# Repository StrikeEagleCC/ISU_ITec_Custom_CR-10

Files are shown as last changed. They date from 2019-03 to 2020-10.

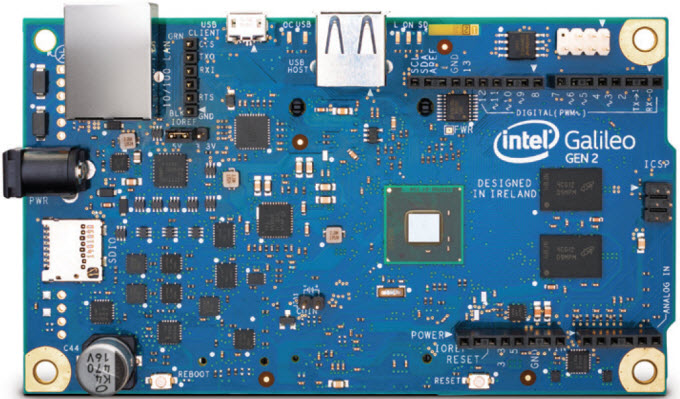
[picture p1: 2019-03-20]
Arduino Windows Preconfigured/reference/Edison_help_files/Guide_Windows_html_14b9dfe7.jpg

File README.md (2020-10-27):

# ISU_ITec_Custom_CR-10
Firmware, information, and slicer profiles for the ISU ITec club custom Creality CR-10's
https://github.com/StrikeEagleCC/ISU_ITec_Custom_CR-10

## 2020 UPDATE
- Switched to a flexible, removable magnetic print surface
- Restored full build volume through better implementation of homing and mesh probing
- Reverted back to bed springs instead of nylon spacers to reduce severity of crashes, and used better-than-stock springs
- [New and Improved slicer profiles!](https://github.com/StrikeEagleCC/ISU_ITec_Custom_CR-10/tree/master/Slicer%20Profiles)
- Replaced Slic3r profiles with PrusaSlicer profiles

To make additional changes to the firmware simple, I have included in this repository a portable installation of the Arduino IDE which has been preconfigured to work for Creality CR and Ender series printers. To edit the firmware, download this repository and open "OpenFirmwareWindows.bat"

Special thanks to Michael from the YouTube channel [Teaching Tech](https://www.youtube.com/channel/UCbgBDBrwsikmtoLqtpc59Bw) and Chris from [TH3D](https://www.th3dstudio.com/) for their excellent guides and other resources. And of course, to the Marlin developer community for all of their excellent work.

---

The two Creality CR-10s belonging to the ISU Itec Club Robotics Team have been modified in several notable ways that you should be aware of.

## The most important things to know are:

1. **Add `G29` to your starting scripts!** (But only after commands to fully heat the bed, i.e. M190)
1. **The flexible magnetic print surfaces work well for PLA and PETG. However, you can still use the ULTRABASE glass surface. Simply remove the magnetic sheet and replace with the glass.**
1. **When placing the manetic print surface on the bed, ensure there is no debris between the print surface and the bed. This is especially important if the printers continue to be stored in the CNC lab, as metal chips will be attracted to the magnetic surfaces.**
1. **Do not use metal scrapers on the ULTRABASE glass print surface! Allow it to cool completely and parts will pop off easily.** If parts are not coming off easily, the first layer may be getting too squashed.
1. **If using the glas print surface, don't attempt to print close to the front or back edge of the bed. The print head will hit the clips that hold the glass to the bed.**
1. **The shape of the bed will continue to change for several minutes after preheating has completed. Allow several minutes at full temperature before starting the bed-leveling probing.** This can be done by adding delays to starting scripts. Read more below.
1. **The bed leveling knobs do not need to be adjusted. They have been carefully set and locked with jam nuts. Any remaining out-of-level condition should be compensated for by the BLTouch probe and software bed leveling**
1. **The height of the nozzle above the bed can be adjusted from the menus to dial in the height of the first layer in real time:**
    1. _Control>Motion>Probe Z Offset_
    1. **Or** by double-clicking or long-clicking the control knob during a print (making live adjustments this way is called "baby-stepping")
1. **Each printer controller is paired with a particular printer frame due to the** **_Probe Z Offset_**  **setting being unique to each printer. Don't mix them up.** I have labeled both frames and both controllers to make this obvious.

The modifications on these machines were made for the sake of adding several desirable features for both safety and functionality. However, given the low price point of the printers, some trade-offs had to be made. I'll list new features and lost features below, and then discuss in further detail. The changes included some new hardware, modification of original hardware, and installation of a customized version of the Marlin firmware

**New Features**

- Thermal runaway protection for both bed and extruder
- BLtouch probe
- Automatic mesh bed leveling
- Linear pressure control
- Filament runout detection
- Persistent settings

**Lost Features**

- Buzzer no longer functional
- Some menu items no longer visible
  - Any functions for which menu items were removed are still accessible through Gcode, either through GCode files or through a serial console like pronterface or Simplify3D's machine control panel.
- No arc support
- No volumetrics

---

### New Features In Detail

#### Thermal Runaway Protection
Thermal runaway protection is an important safety feature that was not included in the original printer firmware. This feature prevents the bed or extruder from overheating in the event that a temperature sensor fails. This type of failure has been the cause of 3D printer fires in the past, and is now widely considered to be a critical safety feature. This is just a software feature, and required no hardware modifications. This feature also requires no interaction with the user. [Read more here.](http://marlinfw.org/docs/configuration/configuration.html#safety)

#### BLTouch Probe
The BLTouch probe is the device on the hotend carriage with the red light in it. This device uses a small solenoid, a pin, and a hall effect sensor to measure the position of the print bed relative to the nozzle. In the simplest implementation, it just replaces the Z-axis limit switch, but its true value is that it facilitates automatic mesh bed leveling.

**Using a Z-axis probe creates an additional and very important setting, _Probe Z Offset_.** This setting represents the distance between the probe's measurement point and the bottom of the nozzle. It can be adjusted from the menus _Control>Motion>Probe Z Offset_ or by double-clicking or long-clicking the control wheel during a print. This is extremely handy to make fine adjustments to the nozzle height during the first layer.

Under some circumstances, the probe may encounter an error and begin flashing. This error can be cleared by either power cycling the printer or navigating to the BLTouch sub menu and resetting it: _Control>BL Touch>Reset BL Touch_

Installing the probe requires the use of a pin on the printer's microprocessor which was previously used to sound the buzzer. To make the use of the probe possible, the buzzer has been disabled, and the pin repurposed for use with the probe.Read more about [probes in Marlin](http://marlinfw.org/docs/configuration/configuration.html#z-probe-options) and more about the [BLTouch](https://www.antclabs.com/bltouch).

#### Automatic Mesh Bed Leveling
Auto bed leveling is a process that makes it possible to get reliable first layers, even on beds that aren't perfectly flat or level. This is done by taking several z-axis measurements of the print bed when starting a print. The printer then uses these measurements to build a map of the print bed, then automatically adjusts the nozzle height during printing to conform to the shape of the bed. This effect can be gradually faded out so that after a short vertical distance it is no longer in effect.

Mesh bed leveling compensates both for beds that aren't flat and beds that aren't level. This means that the bed doesnt have to be perfectly level. As long as the jam nuts beneath the leveling knobs are snug, no adjustment should be needed.

**An important limitation** of thes printers is the cantilevered design of the X-axis gantry. Because the Z leadscrew only pushes on the left side of the X gantry, there is some movement hysteresis (backlash) on the right side. This hysteresis can have a negative impact on the effectiveness of bed leveling, since the probing is done with the gantry moving downwards, and the prints are done with the gantry moving upwards. In practice, I find that even after an automatic bed leveling, my first layers are a bit thinner on the right side of the bed than on the left. Some careful adjustment of the X-axis gantry rollers has improved this somewhat. Still, it's better than stock in that it compensates for the non-planer shape of the bed. **Don't attempt first layers thinner than 0.2mm unless the print is very small** The thicker the first layer is, the more room there is for error here.

Mesh bed leveling should be performed at the beginning of every print. This is done by adding a `G29` command in the starting script in the slicer _after_ the bed has finished heating. Failure to add this will almost certainly lead to first layer failure, may lead to a crash and to nozzle or bed damage. Also, as noted previously, the bed will continue to change shape for several minutes after preheating has completed. This is due primarily to thermal expansion and the time it takes for the bed temperature to even out. To allow for this, add a delay before `G29` in the starting script with `G4 P<time in milliseconds>`. Delays greater than 60 seconds may cause problems in some scenarios, so for a 5 minute delay, add `G29 P60000` five times in the starting script.

Mesh bed leveling is done in software, but requires the use of a probe such as the BLTouch. You can [read more about it here](http://marlinfw.org/docs/configuration/configuration.html#bed-leveling).

#### Linear Pressure Control
Also called Linear Advance, this feature aims to improve print quality by controlling the pressure in the nozzle. This is done by adding compression to the filament in an amount proportional to the extrusion velocity and a controlled by a constant factor configurable in the machine settings. There is a lot of interesting [information available about it here](http://marlinfw.org/docs/features/lin_advance.html), but here's what you need to know:

Linear advance causes a lot of extruder motor movement. If you're familiar with FDM machines, the movement of the extruders on these modified machines may surprise you. The setting to control the amount of linear advance is in _Control>Filament>Advance K_, or by issuing a `M900 K<factor>`. A factor of 0.6 works well for PLA on these printers. Changing this setting to zero will disable the feature. If disabled, you will need to increase retraction distances in the slicer to avoid stringing, and you can expect to see less detail and more blobs in corners than if the feature is enabled.

This feature is entirely software based and required no hardware modifications.

#### Filament Runout Detection
The purpose of filament runout detection is to stop a print in the event that your filament spool runs empty. This has been implemented on these printers with a custom filament sensor mounted on the extruder motor frame. Filament is fed through the sensor module and into the extruder. If the filament runs out, the sensor module will send a signal to the printer, which will stop the print, move the print head to a parking position, unload the filament and prompt the operator for action.

The park, unload, and prompt actions are part of a filament change sequence that can be manually commanded with a `M600` command. In fact, when the filament sensor detects a runout condition, the machine just gives itself an `M600`. You can execute this command deliberately from a console, or better yet, insert it into your gcode at strategic places to facilitate the use of multiple filament colors in a single print.

The current runout sensor that I designed is not very good. When the filament runs out, it usually jams in the sensor housing when the printer tries to automatically unload it. If this happens, cut the filament between the sensor and the extruder and pull the piece from the sensor out the extruder side. Heat up the extruder and then pull the remaining filament out from the extruder. Install the new filament as usual.

Also, if the filament is very curly when feeding it into the sensor, it can become snagged. Straighten the filament prior to threading it through.

If the sensor becomes damaged or unwanted, just unplug it. If you want to use a different sensor be aware that a firmware modification is likely to be necessary.

The filament sensor required the use of a pin on the microprocessor that was previously unused. A very small wire was soldered to this pin and used as the signal pin for the filament sensor. The M600 command is part of another feature called _Advanced Pause._ You can read more about filament runout sensors [here](http://marlinfw.org/docs/configuration/configuration.html#filament-runout-sensor) and about the advanced pause feature [here](http://marlinfw.org/docs/configuration/configuration.html#advanced-pause)

#### Persistent Settings
The original firmware on these printers did not support persistent settings. You could make changes to the settings from the menus or by issuing applicable commands, but if the printer was powered cycled, those settings would be replaced by the default values.

To store settings such as _Probe Z Offset_ or _Advance K_ (linear advance factor), navigate to _Control>Store Settings_, or issue an `M500` command from a console. Those settings will now persist through a reboot. To revert to the default settings, select _Restore failsafe_ or issue an `M502` command from a console. **Note** : **this will reset your _Probe Z-Offset_ to zero, and you will have to reset it!** Restoring default settings will not overwrite the stored settings unless you follow `M502` with `M500`

If you make changes to settings and want to revert them to the stored settings, just power cycle the printer or issue an `M501` command to restore the stored settings.

---

### Lost Features In Detail

#### Buzzer No Longer Functional
The buzzer was disconnected so that its control pin could be used for the Z probe

#### Some Menu Items No Longer Visible
Part of keeping the price of these printers low meant using inexpensive electronics. The microcontroller for the CR-10 (and most Creality printers) is cheap, and does not have enough memory to store a fully featured firmware. In order to make space for the new features, some other features were disabled. Most prominently, several menu items are gone.

The most noticeable menu items missing are feedrate, acceleration and jerk settings in the motion menu. Other settings no longer accessible through the menu include motor steps per mm, PID settings, material preset temps, and probably some others I haven't noticed.

These settings can still be changed with the appropriate g-code commands, and then saved to the EEPROM by sending `M500` or by navigating to _Control>Store settings_, you just won't be able to change the settings from the menu.

#### No Arc Support
Barely worth mentioning, since most slicers don't output arc commands by default. Disabled to save space.

#### No Volumetrics
Volumetric extrusion is a feature that allows gcode for a given print to specify the volume of plastic to be extruded through the nozzle, as opposed to the length of filament driven by the extruder. This allows the same g-code file to be used on multiple printers using different diameter filaments or different extruders. If you need it, then you probably know what it is, but it's rarely used. Disabled to save space.

### Printer Default Values

These are the default values that will be loaded if you click _Control>Restore failsafe_. Note that these settings will not persist through a reboot unless you store them with _Control>Store Settings_.

```
G21    ; (mm)
M149 C ; Units in Celsius
Steps per unit:
M92 X80.00 Y80.00 Z400.00 E93.50
Maximum feedrates (units/s):
M203 X500.00 Y500.00 Z20.00 E100.00
Maximum Acceleration (units/s2):
M201 X2000 Y2000 Z100 E5000
Acceleration (units/s2): P<print_accel> R<retract_accel> T<travel_accel>
M204 P100.00 R1500.00 T1500.00
Advanced: Q<min_segment_time_us> S<min_feedrate> T<min_travel_feedrate> X<max_x_jerk> Y<max_y_jerk> Z<max_z_jerk> E<max_e_jerk>
M205 Q20000 S0.00 T0.00 X10.00 Y10.00 Z0.40 E15.00
Home offset:
M206 X0.00 Y0.00 Z0.00
Auto Bed Leveling:
M420 S0 Z0.00
Material heatup parameters:
M145 S0 H195 B60 F127
M145 S1 H230 B70 F127
PID settings:
M301 P24.37 I1.98 D74.89
M304 P916.00 I177.00 D1181.00
Z-Probe Offset (mm):
M851 Z0.00
Linear Advance:
M900 K0.6
Filament load/unload lengths:
M603 L0.00 U550.00
```

---

## Other Useful Information

###  New Plug Pinouts

These pictures are **of the plugs on the control box wiring harnesses**, not the plugs from the devices.

#### BLTouch Plug
BLTouch Plug Pins

Pin | Function
:---: |---
1 | No contact
2|Z-axis endstop signal
3|Ground
4|BLTouch servo signal
5|+5V
6|Ground

Pin 2 connects to the same port on the board as the Z-axis endstop switch used to. The BLTouch uses it to signal when the probe pin has been depressed. Pin 4 is connected to pin 27 on the motherboard, and is used to tell the BLTouch to deploy or retract the probing pin.

#### Filament Runout Plug
Filament Runout Pins

Pin | Function
:---:|---
1|Ground
2|+5V
3|Signal

Pin 3 is connected to pin 29 on the motherboard. It is used to sense the presence of filament. The firmware interprets the state of the signal pin as follows:

Pin State|Runout State
---|---
High (floating, has internal pullup)|Filament present
Low (grounded)|Filament out

If a different runout sensor is purchased or made that uses an inverted scheme, the logic can be inverted in the firmware.

#### Other Non-Stock Parts
Part|Detail|Source
---|---|---
Flexible Magnetic Print Surface|Creality|[amazon.com](https://www.amazon.com/gp/product/B07GZ7QQTS/ref=ppx_yo_dt_b_search_asin_title?ie=UTF8&psc=1)
Black Glass Bed|Anycubic Ultrabase|[Anycubic3D.com](https://www.anycubic.com/collections/heated-bed-glass-plate/products/platform-tempered-glass-plate-310mmx310mm-for-large-print-size)
Bowden tube|Capricorn XS|[captubes.com](https://www.captubes.com/shop/#!/2-Meters-XS-Low-Friction-1-75mm-Bowden-Tubing/p/82434216/category=23214267)
Tube fittings|Capricorn|See above
Bed Springs|FYSETC|[amazon.com](https://www.amazon.com/gp/product/B07GXC1G2B/ref=ppx_yo_dt_b_search_asin_title?ie=UTF8&psc=1)
Silicone Sock|Creality|[amazon.com](https://www.amazon.com/gp/product/B07HP2SWJX/ref=ppx_yo_dt_b_search_asin_title?ie=UTF8&psc=1)
Filament Runout Sensor|Custom Design
Fan Duct|Petsfang Bullseye|[thingiverse.com](https://www.thingiverse.com/thing:2759439)
Bed Leveling Knobs||Unknown
Bed Cable Strain Relief||Unknown

### Potential Replacement Parts

Part Name|Replacement Mfg|Mfg P/N|Source
---|---|---|---
Hotend Fan*|Delta Electronics|AFB0412VHA-A|[digikey.com](https://www.digikey.com/en/products/detail/delta-electronics/AFB0412VHA-A/2743418)
Part Cooling Fan*|Delta Electronics|BFB0412HHA-A|[digikey.com](https://www.digikey.com/product-detail/en/delta-electronics/BFB0412HHA-A/603-1363-ND/2560487)
Power Supply*|MEAN WELL|LRS-12-350|[digikey.com](https://www.digikey.com/product-detail/en/mean-well-usa-inc/LRS-350-12/1866-3344-ND/7705030)
Board Fan*|Sunun Fans|	MF50151V1-1000U-A99|[digikey.com](https://www.digikey.com/product-detail/en/sunon-fans/MF50151V1-1000U-A99/259-1817-ND/7652225)
Enclosure Fan|Delta Electronics|EFB0412MD|[digikey.com](https://www.digikey.com/product-detail/en/delta-electronics/EFB0412MD/603-1853-ND/2328336)

**Notes:**
 
 *The board fans have already been replaced in both printers
 *The part cooling fans have already been replaced in both printers
 *The hotend fans have already been replaced on both printers
 *The power supply has already been replaced in one printer
 
 If the hotend fan needs replacement, don't try to get a super high flow upgrade. Too much cooling can be a problem.  Regardless of which fan is used to replace it, printing temperatures may need adjustment.
 
 The part specified for the cooling fan *should* have more flow and higher pressure than the stock fan. Fan speeds and/or print temperatures may require adjustment after replacement. Generally, PLA does well with lots of cooling though. Get the most powerful fan that will fit.
 
 The power supplies supplied with these printers are garbage. While they do function, they make clicking and squealing noises, and the fans can vibrate like crazy. I found loose balls of solder in one of them. I've opened both and don't think they pose a serious safety risk now that the loose solder has been removed. However, I don't have faith in their longevity. Edit: One has failed already and has been replaced.

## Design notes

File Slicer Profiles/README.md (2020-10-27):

These profiles are not fully tested, but are a good starting point. The most important thing that makes these profiles valuable is the starting and ending scripts and machine definitions. The 'normal' quality settings in Simplify3D and Prusa slicer have been tested with PLA and work well.

One annoying limitation with all of them is that there isn't an easy way to tie material-dependent temperature to speed. The faster plastic is extruded, typically a higher temperature is used. For example, when printing a .12mm thick layer at 40mm/s (2400mm/min), 200°C will work just fine for PLA. However, when printing a .32mm thick layer at 60mm/s (3600mm/min) for the same material may require 215°C or higher. This can't be easily built into a small number of profiles, and therefore, the necessary adjustments are at the discretion of the operator.

Feel free to make your own profiles. Utilize the startup scripts in the README.md in the folders for each of the various slicers.

If you'd like help creating new profiles for any slicer, I'm happy to help. The best way to ask is to open an issue here in Github.

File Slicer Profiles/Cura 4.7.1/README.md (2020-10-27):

# GCode Scripts for Cura

Cura doesn't appear to support exporting printer configurations. To make a printer profile for Cura, you will need the following information to add a custom FFF printer:

Setting Name|Value
---|---
X(Width)|300
Y(Depth)|300
Z(Height)|400
Build plate shape|Rectangular
Origin at center|no
Heated bed|yes
Heated build volume|no
G-code flavor|Marlin
X min|-60
Y min|-22
X max|38
Y max|40
Gantry height|25
Number of Extruders|1
Start G-code|See scripts below
End G-Code|See scripts below
Nozzle size|0.4
Compatible material diameter|1.75
Nozzle offset X|0
Nozzle offset Y|0
Cooling Fan Number|0
Extruder Start G-code|None
Extruder End G-code|None

**Here's a problem with Cura**. . . I think.

I haven't figured out an easy way to use variables in the g-code scripts, so unlike other slicers, if you slice with cura and want the following scripts to work, you have to manually edit the gcode file after saving it. First, delete all the lines that appear before the startup script. Then, replacie 	`[first_layer_bed_temp]` with the temperature you want the bed to be for the first layer and `[first_layer_extruder_temp]` with the temperature you want the extruder to be for the first layer. For example, if you want your bed at 60 degrees and your extruder at 210 degrees:

`M190 S[first_layer_bed_temp]`

`M109 S[first_layer_extruder_temp]`

become:

`M190 S60`

`M109 S210`

**Start G-code**
```
; Startup script for ITec custom CR-10
M220 S100 ; set speed to 100%
M221 S100 ; set filament flow to 100%
M190 S[first_layer_bed_temp] ; Wait for bed to preheat
; Allow several minutes for bed temperature to stabilize.
G4 P60000 ; Wait additional 60 seconds for bed temp to stabilize
G4 P60000 ; Wait additional 60 seconds for bed temp to stabilize
G4 P60000 ; Wait additional 60 seconds for bed temp to stabilize
G4 P60000 ; Wait additional 60 seconds for bed temp to stabilize
G4 P60000 ; Wait additional 60 seconds for bed temp to stabilize
G90 ; Absolute measurement
G28 ; Home all axes
G29 ; Bed leveling
G1 X1 Y29 F18000 ; Move to prime
M109 S[first_layer_extruder_temp] T0; Now wait for extruder to finish preheat
G1 Z0.3 F1000 ; get ready to prime
G92 E0 ; Reset extrusion distance
G1 Y138 E12 F600 ; prime nozzle
G92 E0 ; Reset extrusion distance
```

**End G-code**
```
; Ending script for Itec custom CR-10
G92 E0 ; Reset extrusion distance
G1 E-3.00 F2400 ; Retract
G91 ; incremental measurement
G1 Z1 F1000 ; z-lift from print
G90 ; absolute measurement
G28 X0 ; home x axis
M106 S0 ; turn off cooling fan
M104 S0 ; turn off extruder
M140 S0 ; turn off bed
M84 ; disable motors
```

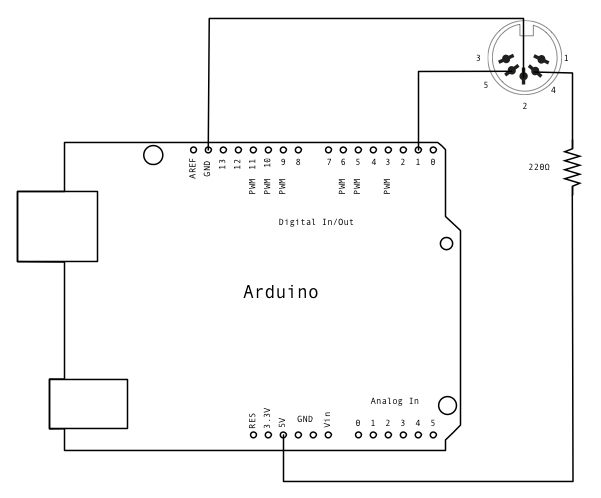
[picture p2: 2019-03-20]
Arduino Windows Preconfigured/examples/04.Communication/Midi/schematic.png

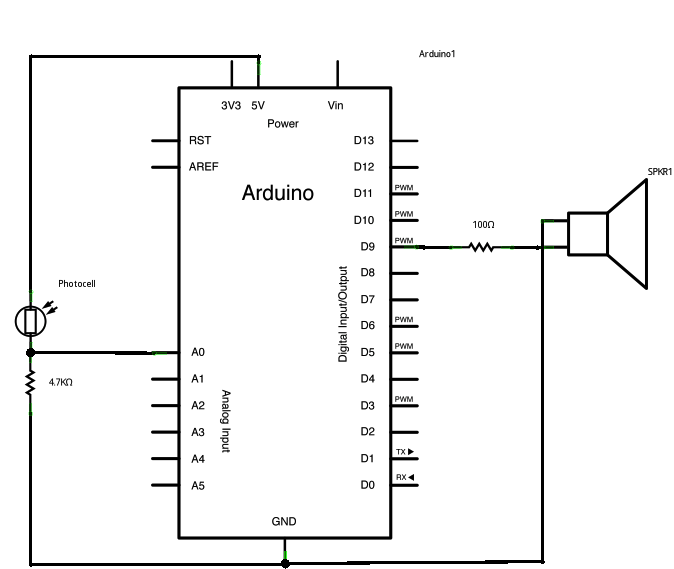
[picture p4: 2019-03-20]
Arduino Windows Preconfigured/examples/02.Digital/tonePitchFollower/schematic.png

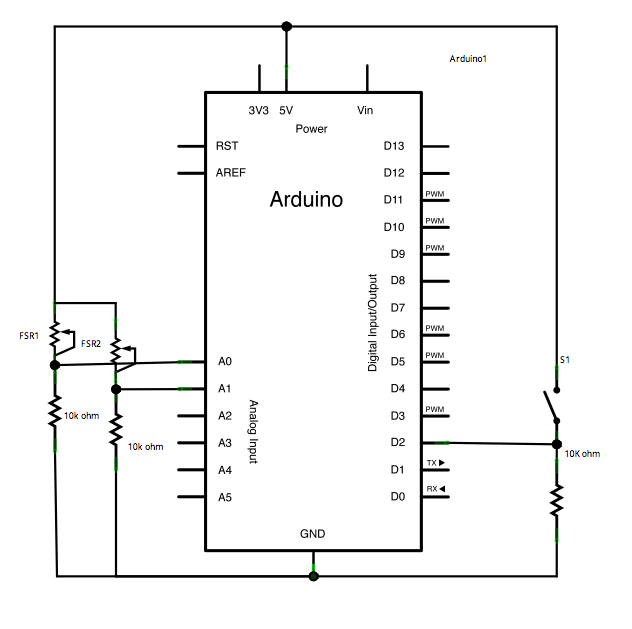
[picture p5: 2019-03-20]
Arduino Windows Preconfigured/examples/04.Communication/SerialCallResponse/schematic.png

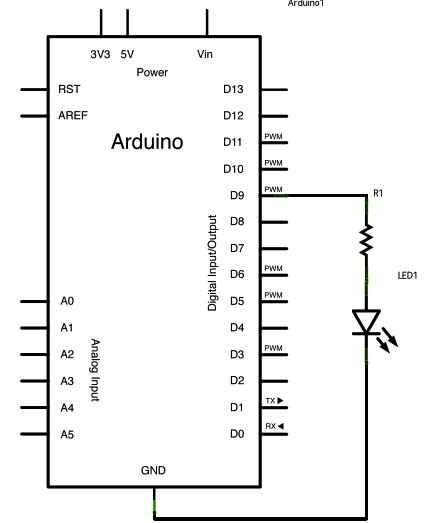
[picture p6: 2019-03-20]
Arduino Windows Preconfigured/examples/04.Communication/Dimmer/schematic.png

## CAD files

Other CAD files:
Slicer Profiles/Cura 3.6.0/Itec CR-10 Cura Project Template.3mf

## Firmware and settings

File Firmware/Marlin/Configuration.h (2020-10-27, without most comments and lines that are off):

#define CONFIGURATION_H
#define CONFIGURATION_H_VERSION 010109
#define STRING_CONFIG_H_AUTHOR "(Ben Gibson)" // Who made the changes.
#define STRING_SPLASH_LINE1 SHORT_BUILD_VERSION // will be shown during bootup in line 1
#define STRING_SPLASH_LINE2 WEBSITE_URL         // will be shown during bootup in line 2
#define SERIAL_PORT 0
#define BAUDRATE 115200
  #define MOTHERBOARD BOARD_MELZI_CREALITY
#define CUSTOM_MACHINE_NAME "ITec CR-10"
#define EXTRUDERS 1
#define DEFAULT_NOMINAL_FILAMENT_DIA 1.75
#define POWER_SUPPLY 0
#define TEMP_SENSOR_0 1
#define TEMP_SENSOR_1 0
#define TEMP_SENSOR_2 0
#define TEMP_SENSOR_3 0
#define TEMP_SENSOR_4 0
#define TEMP_SENSOR_BED 5
#define TEMP_SENSOR_CHAMBER 0
#define DUMMY_THERMISTOR_998_VALUE 25
#define DUMMY_THERMISTOR_999_VALUE 100
#define MAX_REDUNDANT_TEMP_SENSOR_DIFF 10
#define TEMP_RESIDENCY_TIME 10  // (seconds)
#define TEMP_HYSTERESIS 3       // (degC) range of +/- temperatures considered "close" to the target one
#define TEMP_WINDOW     1       // (degC) Window around target to start the residency timer x degC early.
#define TEMP_BED_RESIDENCY_TIME 10  // (seconds)
#define TEMP_BED_HYSTERESIS 3       // (degC) range of +/- temperatures considered "close" to the target one
#define TEMP_BED_WINDOW     1       // (degC) Window around target to start the residency timer x degC early.
#define HEATER_0_MINTEMP 5
#define HEATER_1_MINTEMP 5
#define HEATER_2_MINTEMP 5
#define HEATER_3_MINTEMP 5
#define HEATER_4_MINTEMP 5
#define BED_MINTEMP 5
#define HEATER_0_MAXTEMP 275
#define HEATER_1_MAXTEMP 275
#define HEATER_2_MAXTEMP 275
#define HEATER_3_MAXTEMP 275
#define HEATER_4_MAXTEMP 275
#define BED_MAXTEMP 100
#define PIDTEMP
#define BANG_MAX 255     // Limits current to nozzle while in bang-bang mode; 255=full current
#define PID_MAX BANG_MAX // Limits current to nozzle while PID is active (see PID_FUNCTIONAL_RANGE below); 255=full current
#define PID_K1 0.95      // Smoothing factor within any PID loop
  #define PID_FUNCTIONAL_RANGE 10 // If the temperature difference between the target temperature and the actual temperature
  #define DEFAULT_Kp 24.37
  #define DEFAULT_Ki 1.98
  #define DEFAULT_Kd 74.89
#define PIDTEMPBED
#define MAX_BED_POWER 255 // limits duty cycle to bed; 255=full current
  #define DEFAULT_bedKp 916
  #define DEFAULT_bedKi 177
  #define DEFAULT_bedKd 1181
#define PREVENT_COLD_EXTRUSION
#define EXTRUDE_MINTEMP 170
#define PREVENT_LENGTHY_EXTRUDE
#define EXTRUDE_MAXLENGTH 550
#define THERMAL_PROTECTION_HOTENDS // Enable thermal protection for all extruders
#define THERMAL_PROTECTION_BED     // Enable thermal protection for the heated bed
#define USE_XMIN_PLUG
#define USE_YMIN_PLUG
#define USE_ZMIN_PLUG
#define ENDSTOPPULLUPS
#define X_MIN_ENDSTOP_INVERTING false // set to true to invert the logic of the endstop.
#define Y_MIN_ENDSTOP_INVERTING false // set to true to invert the logic of the endstop.
#define Z_MIN_ENDSTOP_INVERTING false // set to true to invert the logic of the endstop.
#define X_MAX_ENDSTOP_INVERTING false // set to true to invert the logic of the endstop.
#define Y_MAX_ENDSTOP_INVERTING false // set to true to invert the logic of the endstop.
#define Z_MAX_ENDSTOP_INVERTING false // set to true to invert the logic of the endstop.
#define Z_MIN_PROBE_ENDSTOP_INVERTING true // set to true to invert the logic of the probe.
#define DEFAULT_AXIS_STEPS_PER_UNIT   { 80, 80, 400, 93.5 }
#define DEFAULT_MAX_FEEDRATE          { 300, 300, 20, 100 }
#define DEFAULT_MAX_ACCELERATION      { 2000, 2000, 100, 5000 }
#define DEFAULT_ACCELERATION          1000    // X, Y, Z and E acceleration for printing moves
#define DEFAULT_RETRACT_ACCELERATION  1500    // E acceleration for retracts
#define DEFAULT_TRAVEL_ACCELERATION   1500    // X, Y, Z acceleration for travel (non printing) moves
#define DEFAULT_XJERK                10.0
#define DEFAULT_YJERK                10.0
#define DEFAULT_ZJERK                 0.4
#define DEFAULT_EJERK                15.0
#define Z_MIN_PROBE_USES_Z_MIN_ENDSTOP_PIN
#define BLTOUCH
  #define SERVO0_PIN 27
  #define BLTOUCH_DELAY 100   // (ms) Enable and increase if needed
#define X_PROBE_OFFSET_FROM_EXTRUDER -47 // X offset: -left  +right  [of the nozzle]
#define Y_PROBE_OFFSET_FROM_EXTRUDER -11 // Y offset: -front +behind [the nozzle]
#define Z_PROBE_OFFSET_FROM_EXTRUDER 0   // Z offset: -below +above  [the nozzle]
#define MIN_PROBE_EDGE 5
#define XY_PROBE_SPEED 10000
#define Z_PROBE_SPEED_FAST HOMING_FEEDRATE_Z
#define Z_PROBE_SPEED_SLOW (Z_PROBE_SPEED_FAST / 8)
#define MULTIPLE_PROBING 3
#define Z_CLEARANCE_DEPLOY_PROBE    4 // Z Clearance for Deploy/Stow
#define Z_CLEARANCE_BETWEEN_PROBES  4 // Z Clearance between probe points
#define Z_CLEARANCE_MULTI_PROBE     3 // Z Clearance between multiple probes
#define Z_AFTER_PROBING           5 // Z position after probing is done
#define Z_PROBE_LOW_POINT          -2 // Farthest distance below the trigger-point to go before stopping
#define Z_PROBE_OFFSET_RANGE_MIN -3
#define Z_PROBE_OFFSET_RANGE_MAX 0
#define X_ENABLE_ON 0
#define Y_ENABLE_ON 0
#define Z_ENABLE_ON 0
#define E_ENABLE_ON 0 // For all extruders
#define DISABLE_X false
#define DISABLE_Y false
#define DISABLE_Z false
#define DISABLE_E false // For all extruders
#define DISABLE_INACTIVE_EXTRUDER true // Keep only the active extruder enabled.
#define INVERT_X_DIR true
#define INVERT_Y_DIR true
#define INVERT_Z_DIR false
#define INVERT_E0_DIR true
#define INVERT_E1_DIR false
#define INVERT_E2_DIR false
#define INVERT_E3_DIR false
#define INVERT_E4_DIR false
#define Z_HOMING_HEIGHT 5  // (in mm) Minimal z height before homing (G28) for Z clearance above the bed, clamps, ...
#define X_HOME_DIR -1
#define Y_HOME_DIR -1
#define Z_HOME_DIR -1
#define X_BED_SIZE 300
#define Y_BED_SIZE 300
#define X_MIN_POS 0
#define Y_MIN_POS 0
#define Z_MIN_POS 0
#define X_MAX_POS X_BED_SIZE + 17
#define Y_MAX_POS Y_BED_SIZE
#define Z_MAX_POS 400
#define MIN_SOFTWARE_ENDSTOPS
  #define MIN_SOFTWARE_ENDSTOP_X
  #define MIN_SOFTWARE_ENDSTOP_Y
  #define MIN_SOFTWARE_ENDSTOP_Z
#define MAX_SOFTWARE_ENDSTOPS
  #define MAX_SOFTWARE_ENDSTOP_X
  #define MAX_SOFTWARE_ENDSTOP_Y
  #define MAX_SOFTWARE_ENDSTOP_Z
#define FILAMENT_RUNOUT_SENSOR
  #define NUM_RUNOUT_SENSORS   1     // Number of sensors, up to one per extruder. Define a FIL_RUNOUT#_PIN for each.
  #define FIL_RUNOUT_PIN 29
  #define FIL_RUNOUT_INVERTING false // set to true to invert the logic of the sensor.
  #define FIL_RUNOUT_PULLUP          // Use internal pullup for filament runout pins.
  #define FILAMENT_RUNOUT_SCRIPT "M600"
#define AUTO_BED_LEVELING_BILINEAR
  #define ENABLE_LEVELING_FADE_HEIGHT
  #define SEGMENT_LEVELED_MOVES
  #define LEVELED_SEGMENT_LENGTH 5.0 // (mm) Length of all segments (except the last one)
  #define GRID_MAX_POINTS_X 3
  #define GRID_MAX_POINTS_Y GRID_MAX_POINTS_X
  #define FRONT_PROBE_BED_POSITION 19
  #define BACK_PROBE_BED_POSITION 275
#define Z_SAFE_HOMING
  #define Z_SAFE_HOMING_X_POINT (5)    // X point for Z homing when homing all axes (G28).
  #define Z_SAFE_HOMING_Y_POINT (20)    // Y point for Z homing when homing all axes (G28).
#define HOMING_FEEDRATE_XY (20*60)
#define HOMING_FEEDRATE_Z  (20*60)
#define EEPROM_SETTINGS // Enable for M500 and M501 commands
#define EEPROM_CHITCHAT   // Give feedback on EEPROM commands. Disable to save PROGMEM.
#define HOST_KEEPALIVE_FEATURE        // Disable this if your host doesn't like keepalive messages
#define DEFAULT_KEEPALIVE_INTERVAL 2  // Number of seconds between "busy" messages. Set with M113.
#define BUSY_WHILE_HEATING            // Some hosts require "busy" messages even during heating
#define PREHEAT_1_TEMP_HOTEND 195
#define PREHEAT_1_TEMP_BED     60
#define PREHEAT_1_FAN_SPEED   127 // Value from 0 to 255
#define PREHEAT_2_TEMP_HOTEND 230
#define PREHEAT_2_TEMP_BED    70
#define PREHEAT_2_FAN_SPEED   0 // Value from 0 to 255
#define NOZZLE_PARK_FEATURE
  #define NOZZLE_PARK_POINT { (X_MIN_POS + 1), (Y_MIN_POS +1), 20 }
  #define NOZZLE_PARK_XY_FEEDRATE 100   // X and Y axes feedrate in mm/s (also used for delta printers Z axis)
  #define NOZZLE_PARK_Z_FEEDRATE 5      // Z axis feedrate in mm/s (not used for delta printers)
#define PRINTJOB_TIMER_AUTOSTART
#define LCD_LANGUAGE en
#define DISPLAY_CHARSET_HD44780 JAPANESE
#define SDSUPPORT
#define SLIM_LCD_MENUS
#define CR10_STOCKDISPLAY
#define SOFT_PWM_SCALE 0
#define SERVO_DELAY { 300 }

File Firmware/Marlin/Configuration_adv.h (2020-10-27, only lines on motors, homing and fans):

#define E0_AUTO_FAN_PIN -1
#define E1_AUTO_FAN_PIN -1
#define E2_AUTO_FAN_PIN -1
#define E3_AUTO_FAN_PIN -1
#define E4_AUTO_FAN_PIN -1
#define CHAMBER_AUTO_FAN_PIN -1
#define X_HOME_BUMP_MM 5
#define Y_HOME_BUMP_MM 5
#define Z_HOME_BUMP_MM 2
#define HOMING_BUMP_DIVISOR { 2, 2, 4 }  // Re-Bump Speed Divisor (Divides the Homing Feedrate)
#define QUICK_HOME                     // If homing includes X and Y, do a diagonal move initially
#define MICROSTEP_MODES { 16, 16, 16, 16, 16 } // [1,2,4,8,16]
#define DIGIPOT_I2C_MOTOR_CURRENTS { 1.0, 1.0, 1.0, 1.0, 1.0, 1.0, 1.0, 1.0 }  //  AZTEEG_X3_PRO
#define LIN_ADVANCE
  #define LIN_ADVANCE_K   .6  // Unit: mm compression per 1mm/s extruder speed
#define ADVANCED_PAUSE_FEATURE
  #define ADVANCED_PAUSE_PURGE_FEEDRATE        3  // (mm/s) Extrude feedrate (after loading). Should be slower than load feedrate.
  #define ADVANCED_PAUSE_PURGE_LENGTH         50  // (mm) Length to extrude after loading.

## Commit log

2019-03-20 Initial upload
    [Configuration.h, Configuration_adv.h, Itec CR-10 Cura Project Template.3mf]
2019-03-20 Update Firmware to configured version
    [Configuration.h, Configuration_adv.h]
2019-03-20 Add preconfigurd arduino environment
    [Configuration.h, Configuration_adv.h]
2019-03-20 Update README.md
    Add information about the pre-configured Arduino IDE and a note of thanks to Teaching Tech and TH3D
2019-03-21 Tune movement settings
    Increase extruder max feedrate and acceleration and jerk to facilitate higher linear advance settings and faster filament unloads.
    Increased decreased x/y jerk and increased x/y acceleration.
    [Configuration.h, Configuration_adv.h]
2019-03-21 Update README.md
    Update default values to new printer defaults
2019-03-23 Update Configuration.h
    Bring extruder acceleration and jerk back down, as the high values led to missed steps and under extrusion when printing thick layers at high speed.
    [Configuration.h]
2019-03-23 Update S3D profile scripts
    Removed the startup script function that waited to do the final nozzle heating until the bed had been leveled. This was necessary because S3D does not have a separate temperature variable for each te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
2019-03-23 Update S3D profiles
    Revert back to previous starting script, fix layer specific temperatures.
2019-03-24 Increase X/Y jerk
    low jerk led to excessive extruder movement in curves due to linear advance.
    [Configuration.h, Configuration_adv.h]
2019-04-12 Update S3D Profiles
    Fixed problem with multiple temperature presets on same layer, fixed all <stabilizeAtStartup> settings to 0, since temperature stabilization is covered in the startup script. changed startup script to reduce z lift prior to homing x axis
2020-10-26 Change firmware
    Make changes to firmware to accomodate new bed surface and improve performance
    [Configuration_adv.h]
2020-10-26 Increase max acceleration
    [Configuration.h]
2020-10-27 Update Pre-configured Arduino Environment
2020-10-27 Update slicer profiles
    [Itec CR-10 Cura Project Template.3mf]

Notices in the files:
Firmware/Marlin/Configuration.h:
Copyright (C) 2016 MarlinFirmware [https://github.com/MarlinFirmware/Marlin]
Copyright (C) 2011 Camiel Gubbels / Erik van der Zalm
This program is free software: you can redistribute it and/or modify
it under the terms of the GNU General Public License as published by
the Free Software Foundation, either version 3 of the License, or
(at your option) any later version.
